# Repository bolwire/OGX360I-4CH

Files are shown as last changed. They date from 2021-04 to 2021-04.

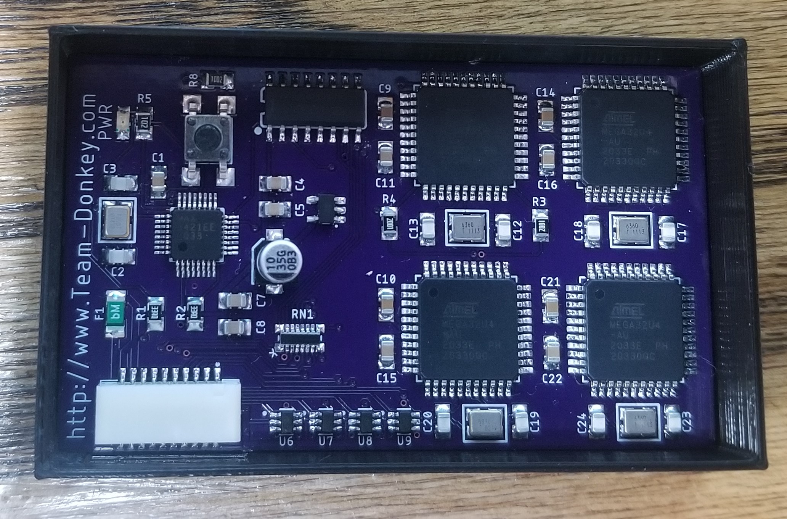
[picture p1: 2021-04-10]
Images/20210410_085733.jpg

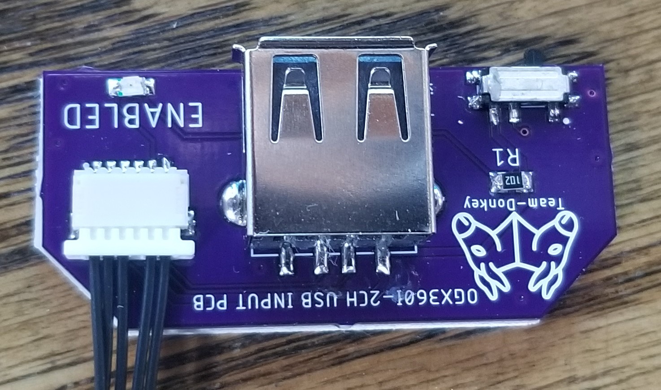
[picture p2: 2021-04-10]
Images/20210410_085617.jpg

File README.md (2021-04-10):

This project builds on the original OGX360 by Ryzee119: https://github.com/Ryzee119/ogx360/

The information provided in this repo is for informational purposes only.

The ATMEGA32U4 chips will need to be programmed with the arduino bootloader before they are put on the PCB. One option may be to remove the chips
from an arduino and transplant them.

Please respect the license files found within this project. What we do, and the joy we gain from that would not be possible without those who shared the
information with us to start with. Please respect and honor that by doing the same with any works derived from this or other projects linked to in this repo.

Also my spelling sucks, so I apologize for any type-ohs that exist.

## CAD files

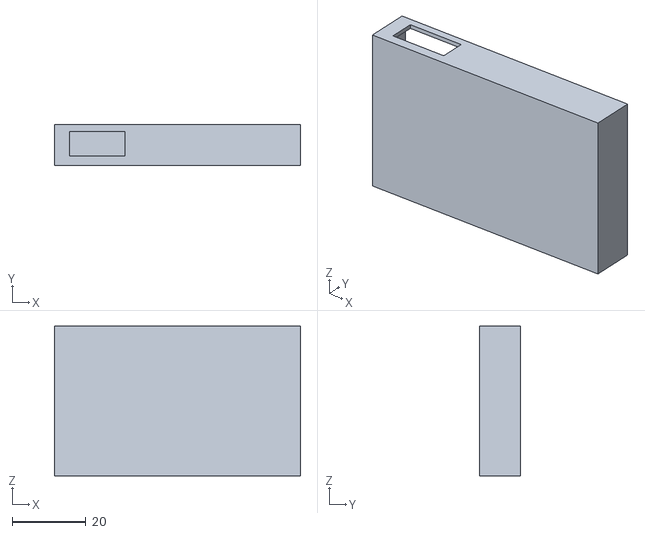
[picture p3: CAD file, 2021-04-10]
Case/Bottom.stl
66.5 x 11.2 x 40.5

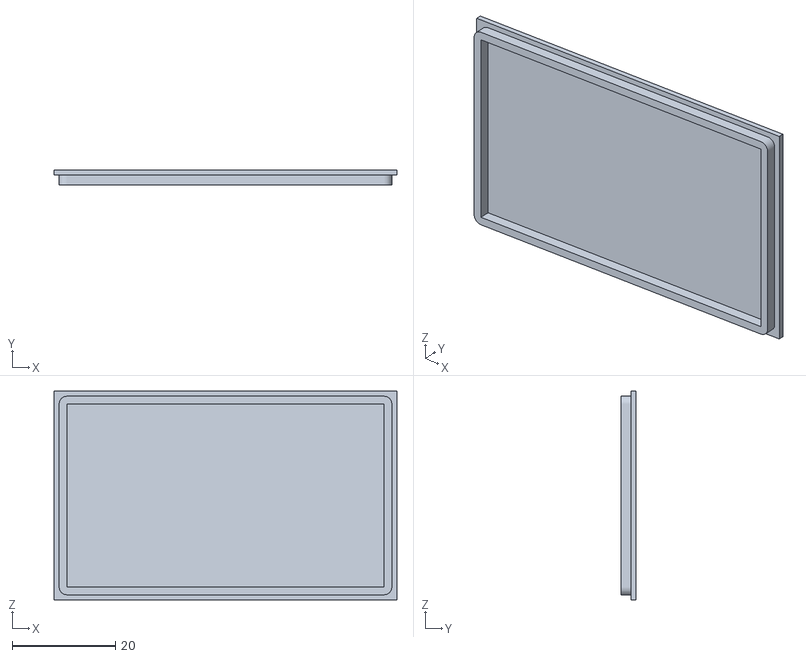
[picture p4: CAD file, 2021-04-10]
Case/Top.stl
66.5 x 3.00 x 40.5

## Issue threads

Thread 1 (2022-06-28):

Any more Documentation?

dtomcat, 2022-06-28:
Is there anymore documentation for this anywhere?  I'd like to make one, but there really isn't any type of instructions, BOM, etc.  Just wanted to know if there is any information elsewhere to help build this?  I can gather most information from the .sch and .brd 's, but some things aren't documented (like x1... x5 freq and cable pinouts (last could probably be interpolated through all the .sch)).  And no mention at all (or photos) of programming utility board...  i'm assuming you jumper DN and DP to whichever player you want to program, but not sure about the ogx_disable jumper.
Thank you for any info

dtomcat, 2023-07-30:
https://github.com/dtomcat/OGX360I-4CH

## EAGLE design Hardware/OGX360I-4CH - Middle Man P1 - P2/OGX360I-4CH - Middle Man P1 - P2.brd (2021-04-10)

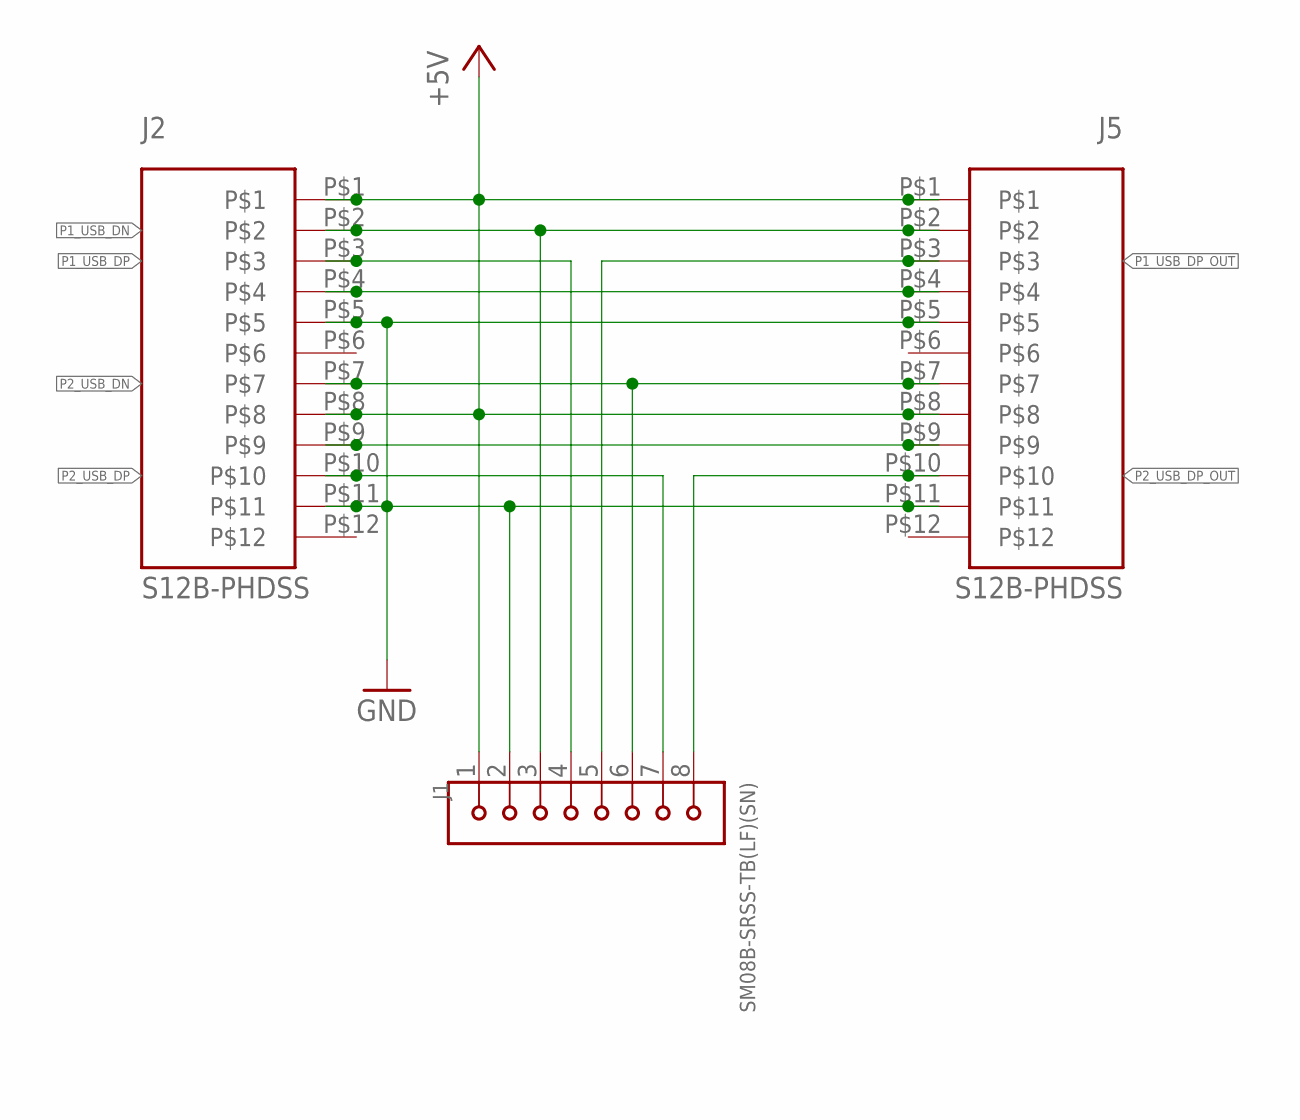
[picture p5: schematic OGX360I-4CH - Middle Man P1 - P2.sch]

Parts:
J1: SM08B-SRSS-TB(LF)(SN); JST_SM08B-SRSS-TB(LF)(SN)
J2, J5: S12B-PHDSS

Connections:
+5V: J1.1, J2.P$1, J2.P$8, J5.P$1, J5.P$8
GND: J1.2, J2.P$5, J2.P$11, J5.P$5, J5.P$11
unnamed: J2.P$4, J5.P$4
unnamed: J2.P$9, J5.P$9
P1_USB_DN: J1.3, J2.P$2, J5.P$2
P1_USB_DP: J1.4, J2.P$3
P1_USB_DP_OUT: J1.5, J5.P$3
P2_USB_DN: J1.6, J2.P$7, J5.P$7
P2_USB_DP: J1.7, J2.P$10
P2_USB_DP_OUT: J1.8, J5.P$10

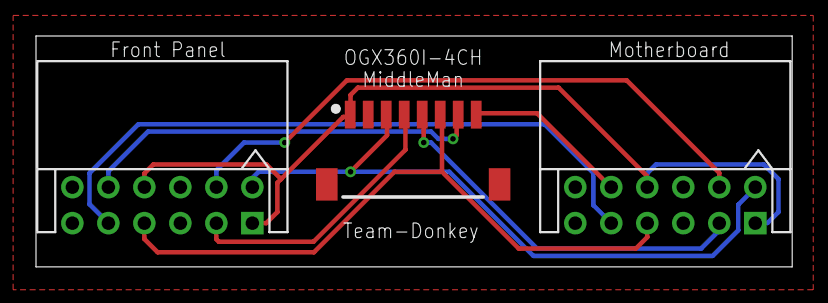
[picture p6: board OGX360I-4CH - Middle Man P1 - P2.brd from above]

Board: 2 copper layers, 42.0 x 12.8 mm, 3 parts (0 on the bottom side), 10 nets.

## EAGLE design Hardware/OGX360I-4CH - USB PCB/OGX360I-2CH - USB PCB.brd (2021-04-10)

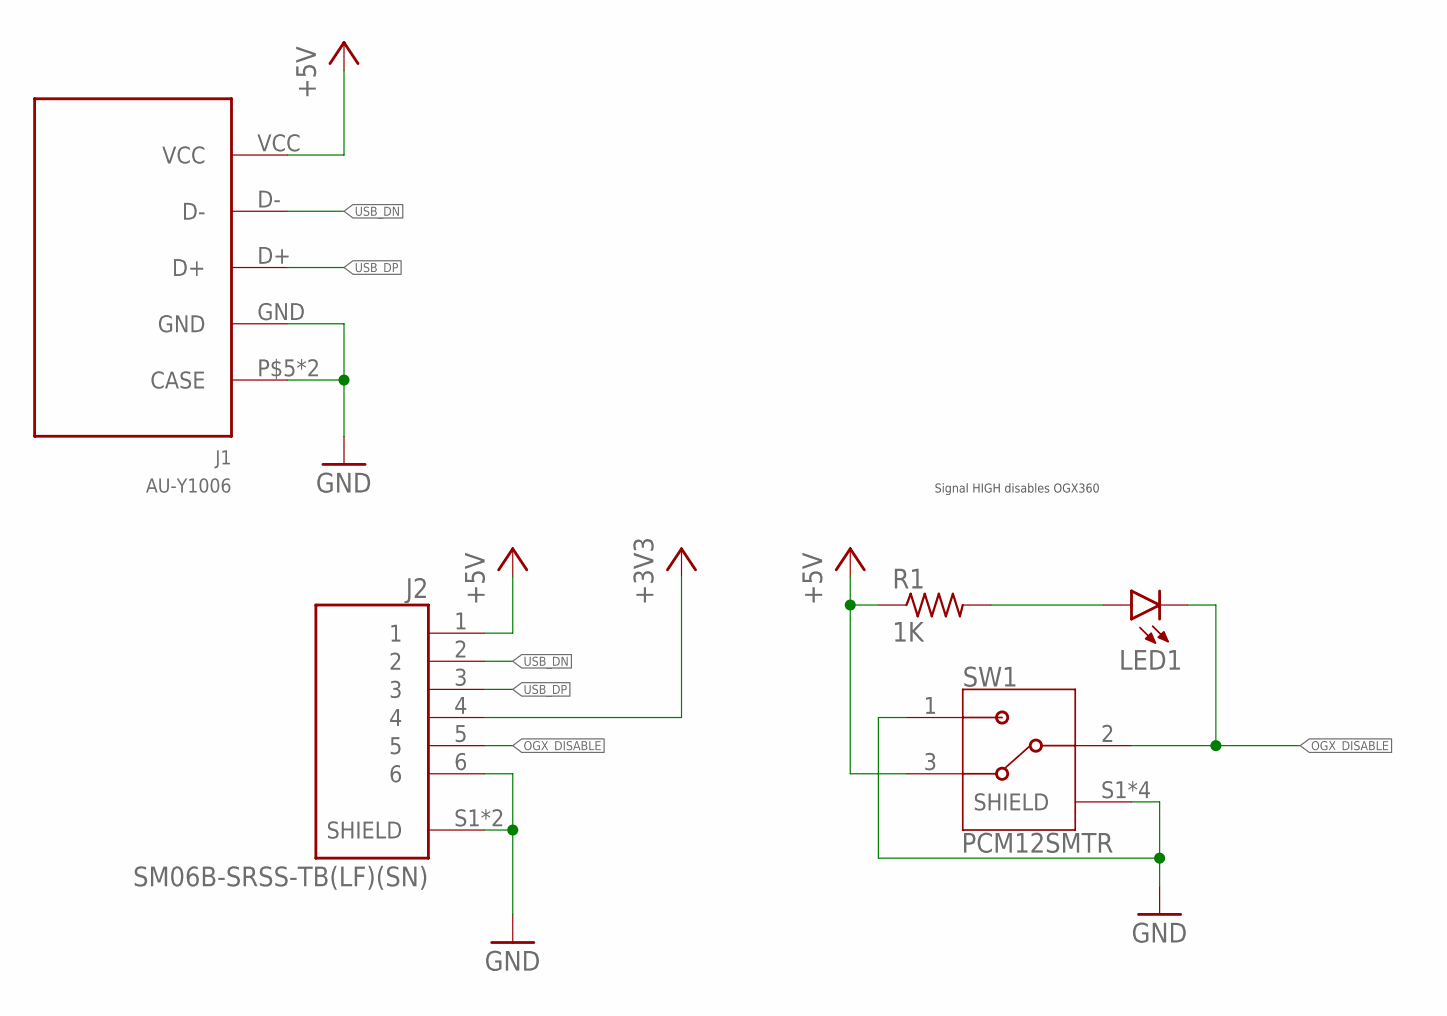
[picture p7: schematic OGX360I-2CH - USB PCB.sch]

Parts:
J1: AU-Y1006; USBA_SMD
J2: SM06B-SRSS-TB(LF)(SN); JST_SM06B-SRSS-TB(LF)(SN)
LED1: LEDCHIP-LED0805; CHIP-LED0805
R1: 1K; R0805
SW1: PCM12SMTR; SW_PCM12SMTR

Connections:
+3V3: J2.4
+5V: J1.VCC, J2.1, R1.1, SW1.3
GND: J1.GND, J1.P$5 (CASE), J1.P$6 (CASE), J2.6, J2.S1 (SHIELD), J2.S2 (SHIELD), SW1.1, SW1.S1 (SHIELD), SW1.S2 (SHIELD), SW1.S3 (SHIELD), SW1.S4 (SHIELD)
unnamed: LED1.A, R1.2
OGX_DISABLE: J2.5, LED1.C, SW1.2
USB_DN: J1.D-, J2.2
USB_DP: J1.D+, J2.3

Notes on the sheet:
Signal HIGH disables OGX360

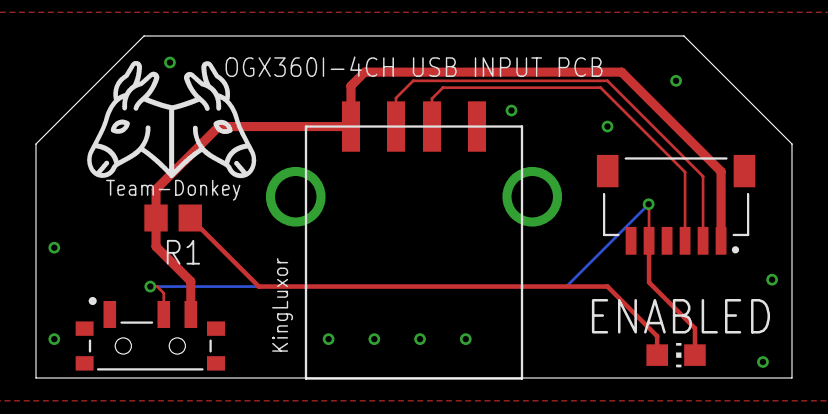
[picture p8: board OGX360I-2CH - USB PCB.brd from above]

Board: 2 copper layers, 42.0 x 19.0 mm, 5 parts (0 on the bottom side), 6 nets.

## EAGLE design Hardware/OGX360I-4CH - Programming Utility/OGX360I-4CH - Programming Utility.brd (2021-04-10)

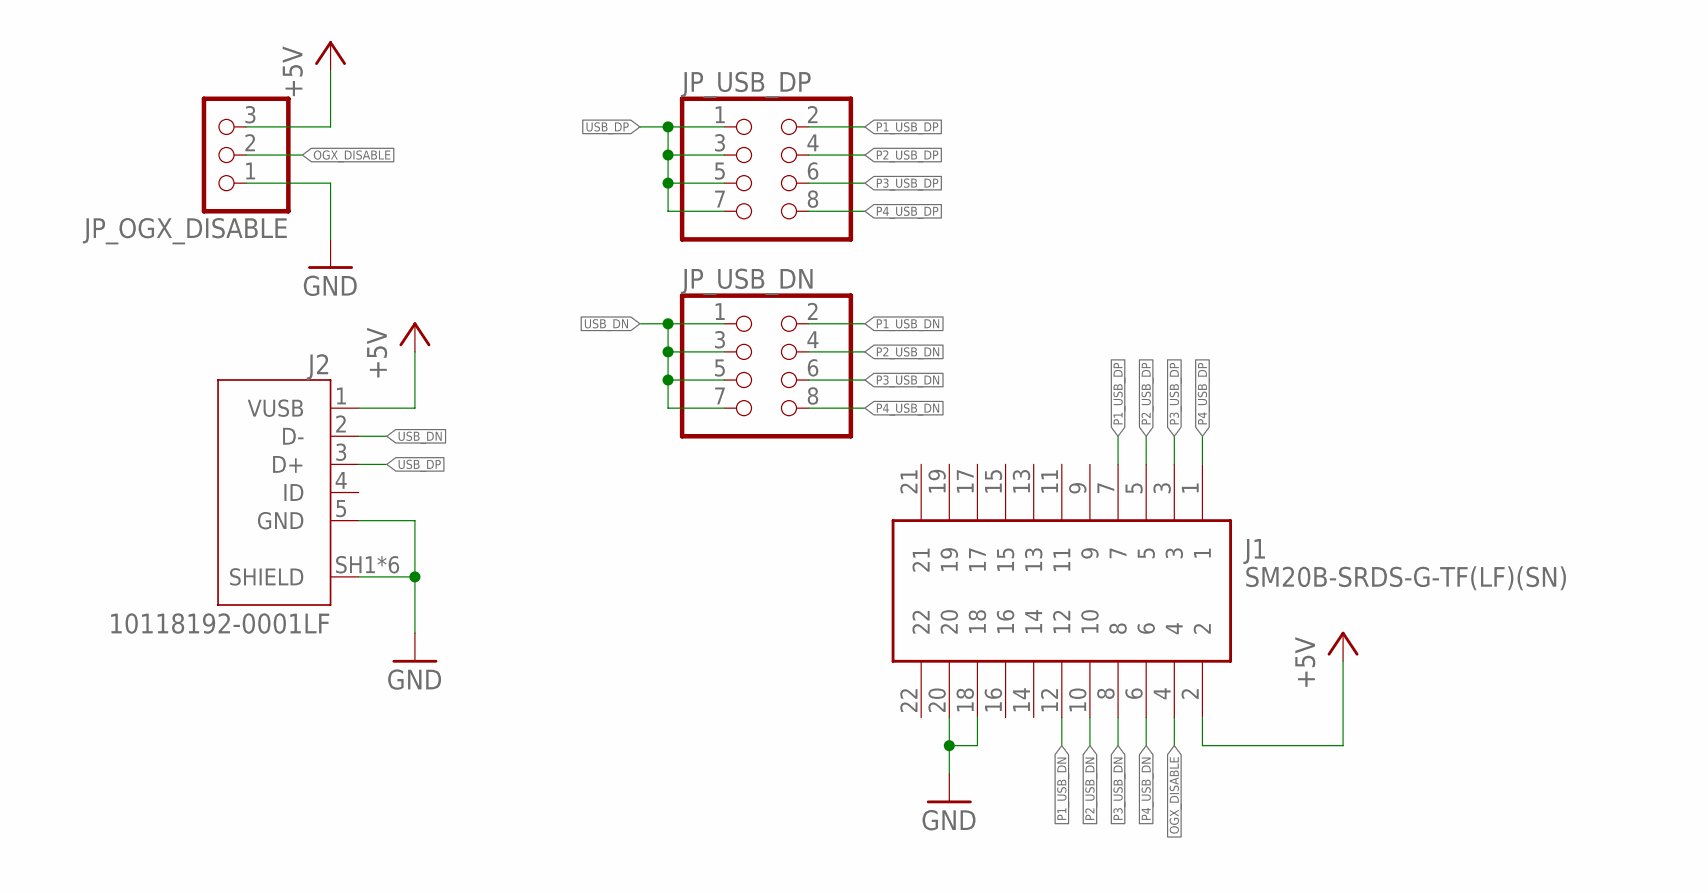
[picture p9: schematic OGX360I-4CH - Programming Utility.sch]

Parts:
J1: SM20B-SRDS-G-TF(LF)(SN); SM20BSRDSGTFLFSN
J2: 10118192-0001LF; AMPHENOL_10118192-0001LF
JP_OGX_DISABLE: PINHD-1X3; 1X03
JP_USB_DN: PINHD-2X4; 2X04
JP_USB_DP: PINHD-2X4; 2X04

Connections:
+5V: J1.2, J2.1 (VUSB), JP_OGX_DISABLE.3
GND: J1.18, J1.20, J2.5 (GND), J2.SH1 (SHIELD), J2.SH2 (SHIELD), J2.SH3 (SHIELD), J2.SH4 (SHIELD), J2.SH5 (SHIELD), J2.SH6 (SHIELD), JP_OGX_DISABLE.1
OGX_DISABLE: J1.4, JP_OGX_DISABLE.2
P1_USB_DN: J1.12, JP_USB_DN.2
P1_USB_DP: J1.7, JP_USB_DP.2
P2_USB_DN: J1.10, JP_USB_DN.4
P2_USB_DP: J1.5, JP_USB_DP.4
P3_USB_DN: J1.8, JP_USB_DN.6
P3_USB_DP: J1.3, JP_USB_DP.6
P4_USB_DN: J1.6, JP_USB_DN.8
P4_USB_DP: J1.1, JP_USB_DP.8
USB_DN: J2.2 (D-), JP_USB_DN.1, JP_USB_DN.3, JP_USB_DN.5, JP_USB_DN.7
USB_DP: J2.3 (D+), JP_USB_DP.1, JP_USB_DP.3, JP_USB_DP.5, JP_USB_DP.7

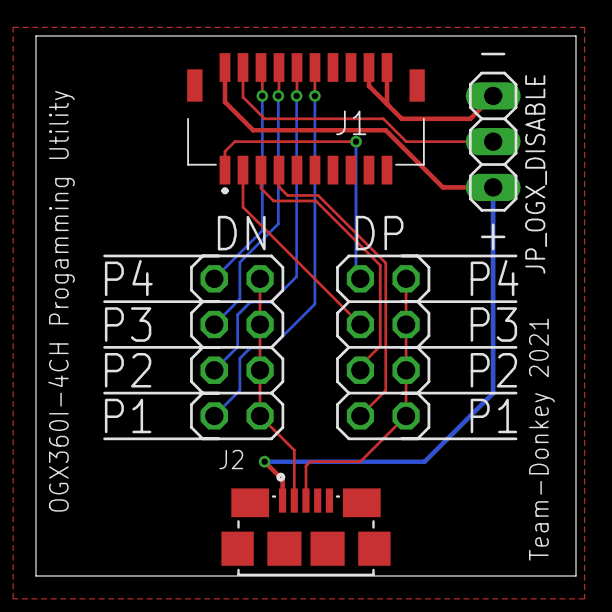
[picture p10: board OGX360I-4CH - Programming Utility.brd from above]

Board: 2 copper layers, 30.0 x 30.0 mm, 5 parts (0 on the bottom side), 13 nets.

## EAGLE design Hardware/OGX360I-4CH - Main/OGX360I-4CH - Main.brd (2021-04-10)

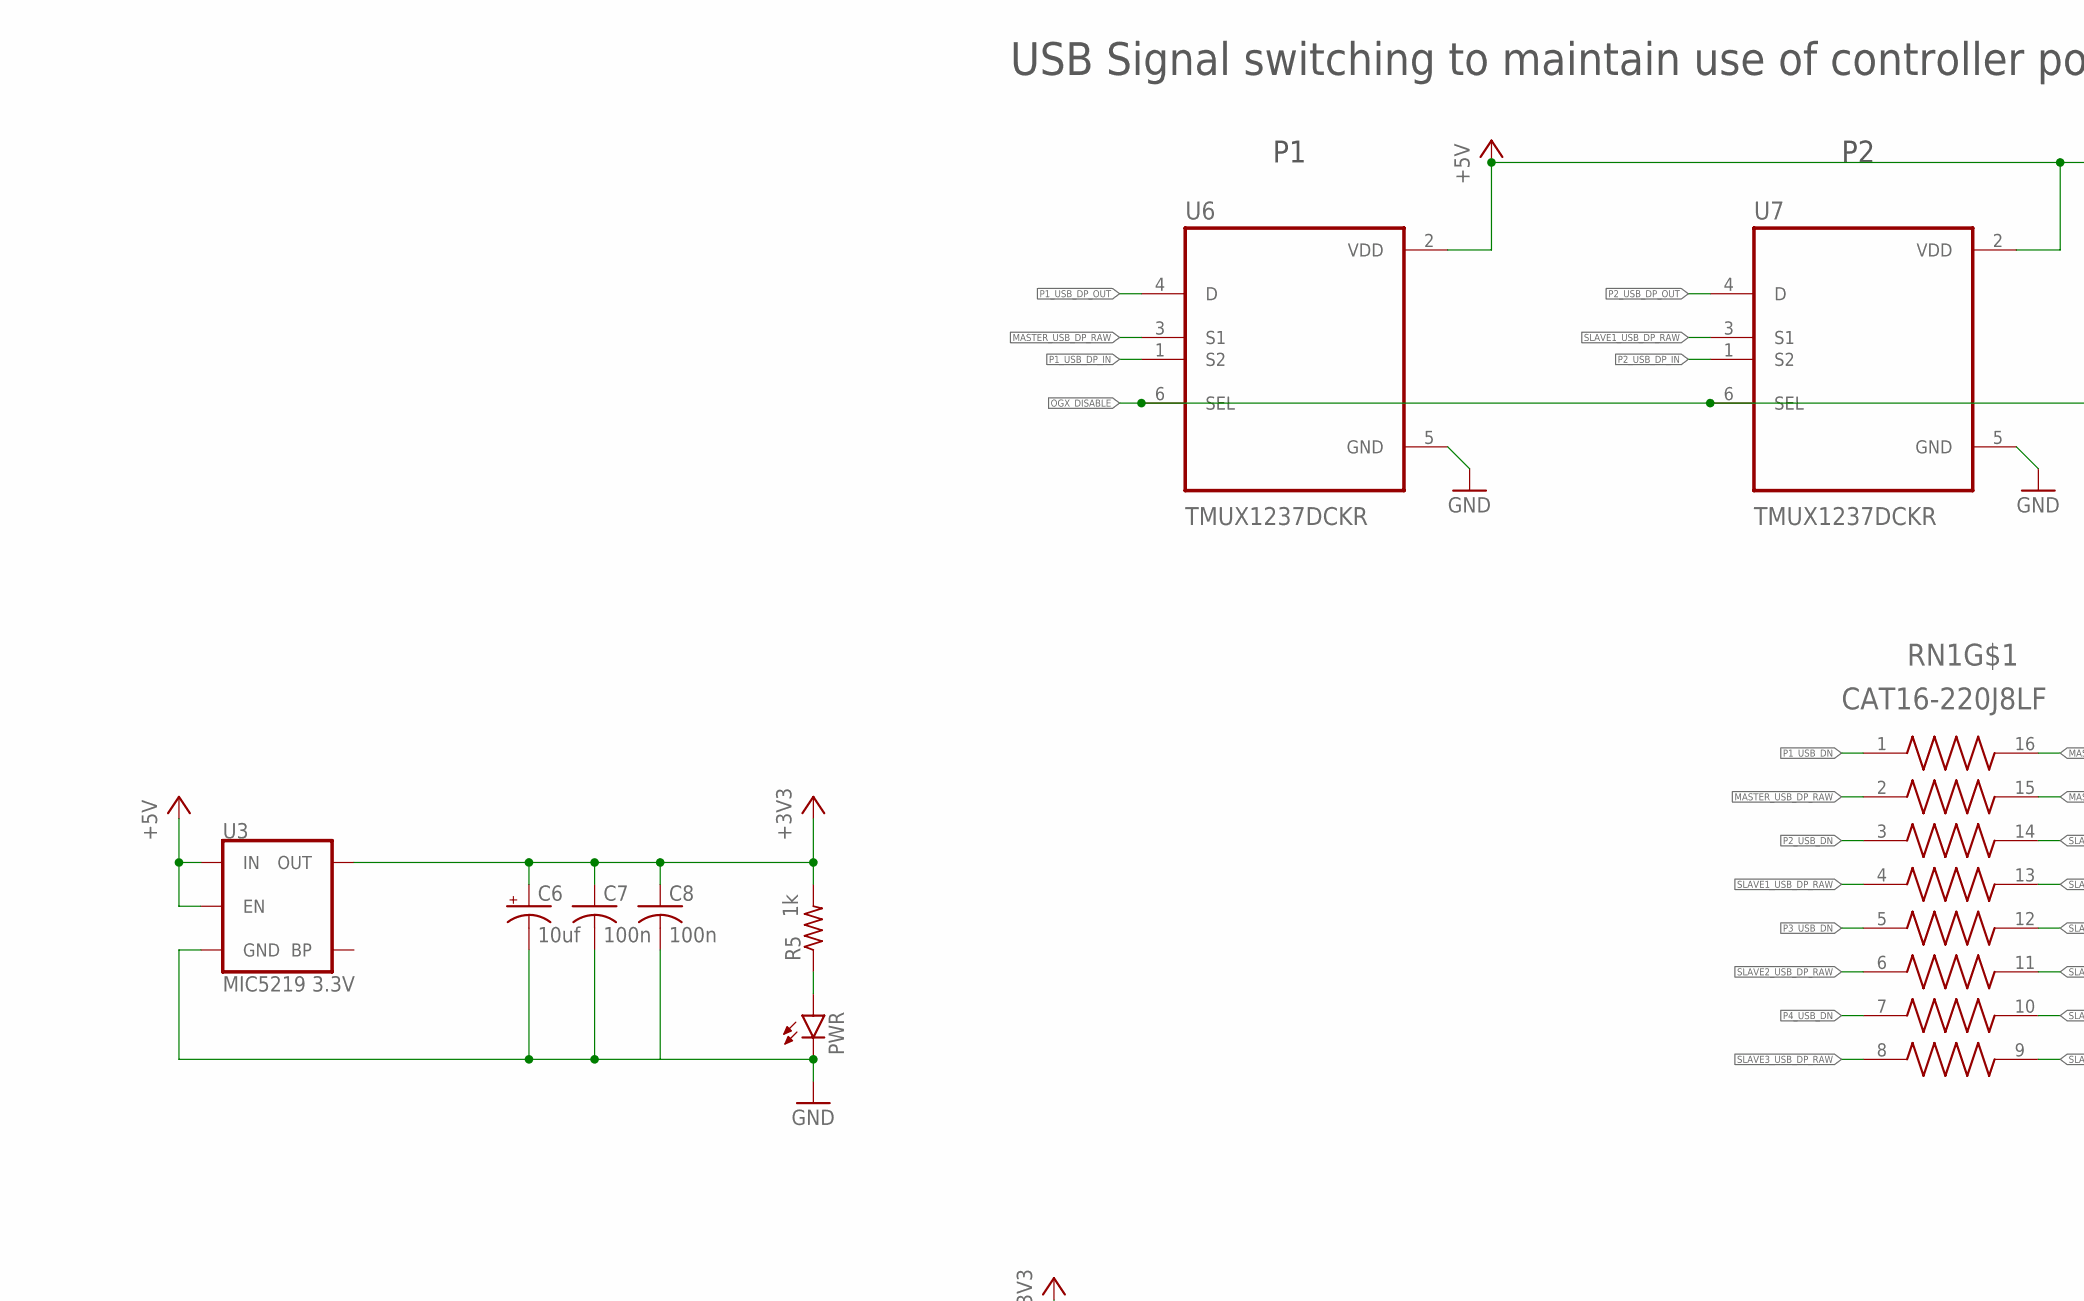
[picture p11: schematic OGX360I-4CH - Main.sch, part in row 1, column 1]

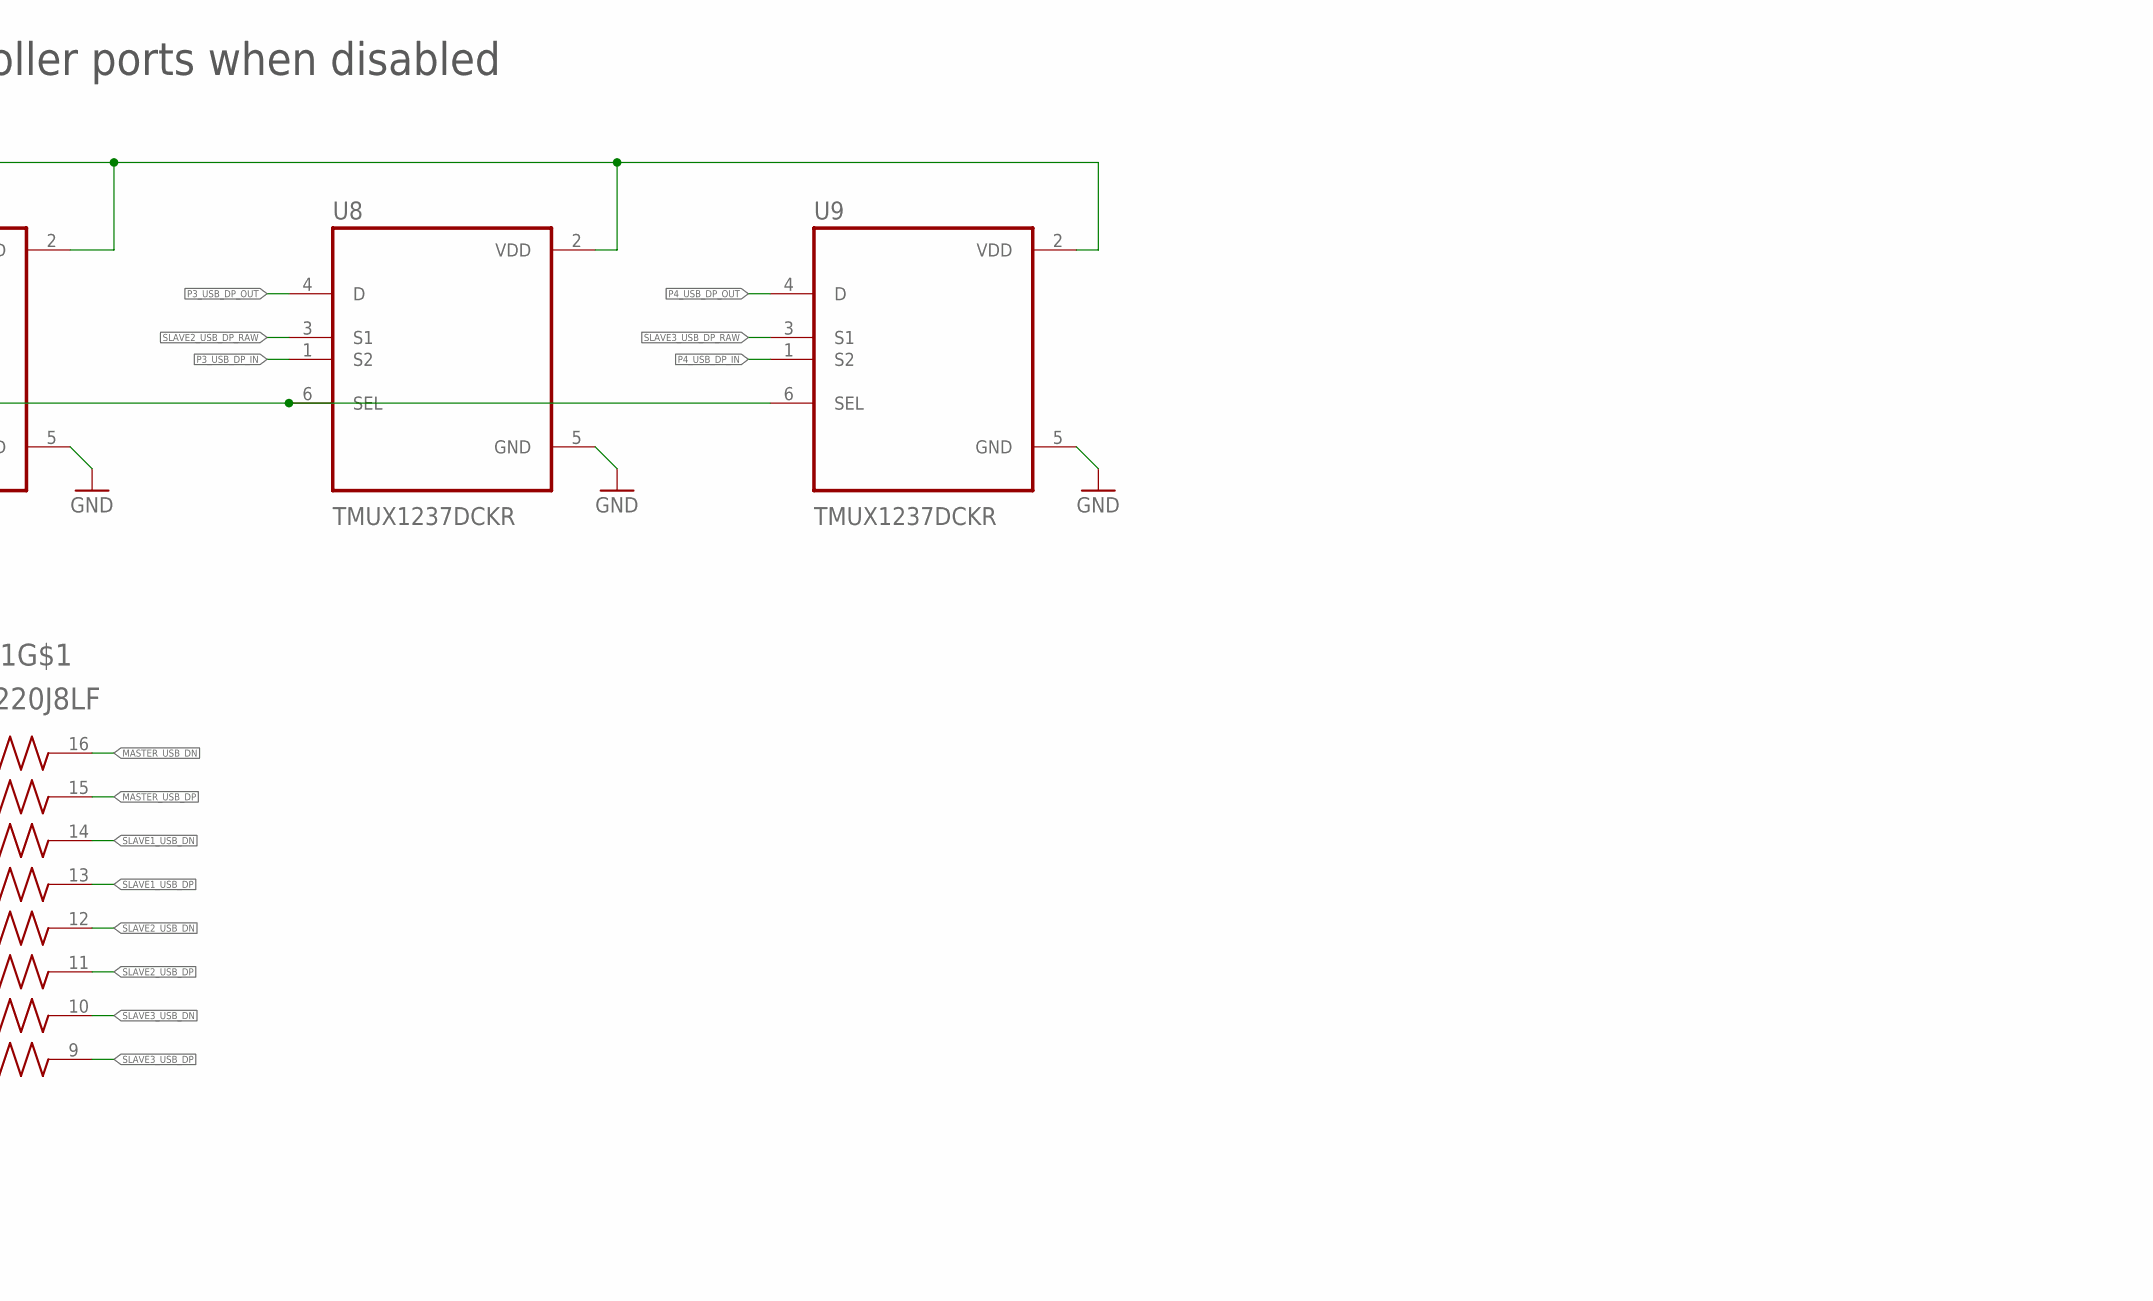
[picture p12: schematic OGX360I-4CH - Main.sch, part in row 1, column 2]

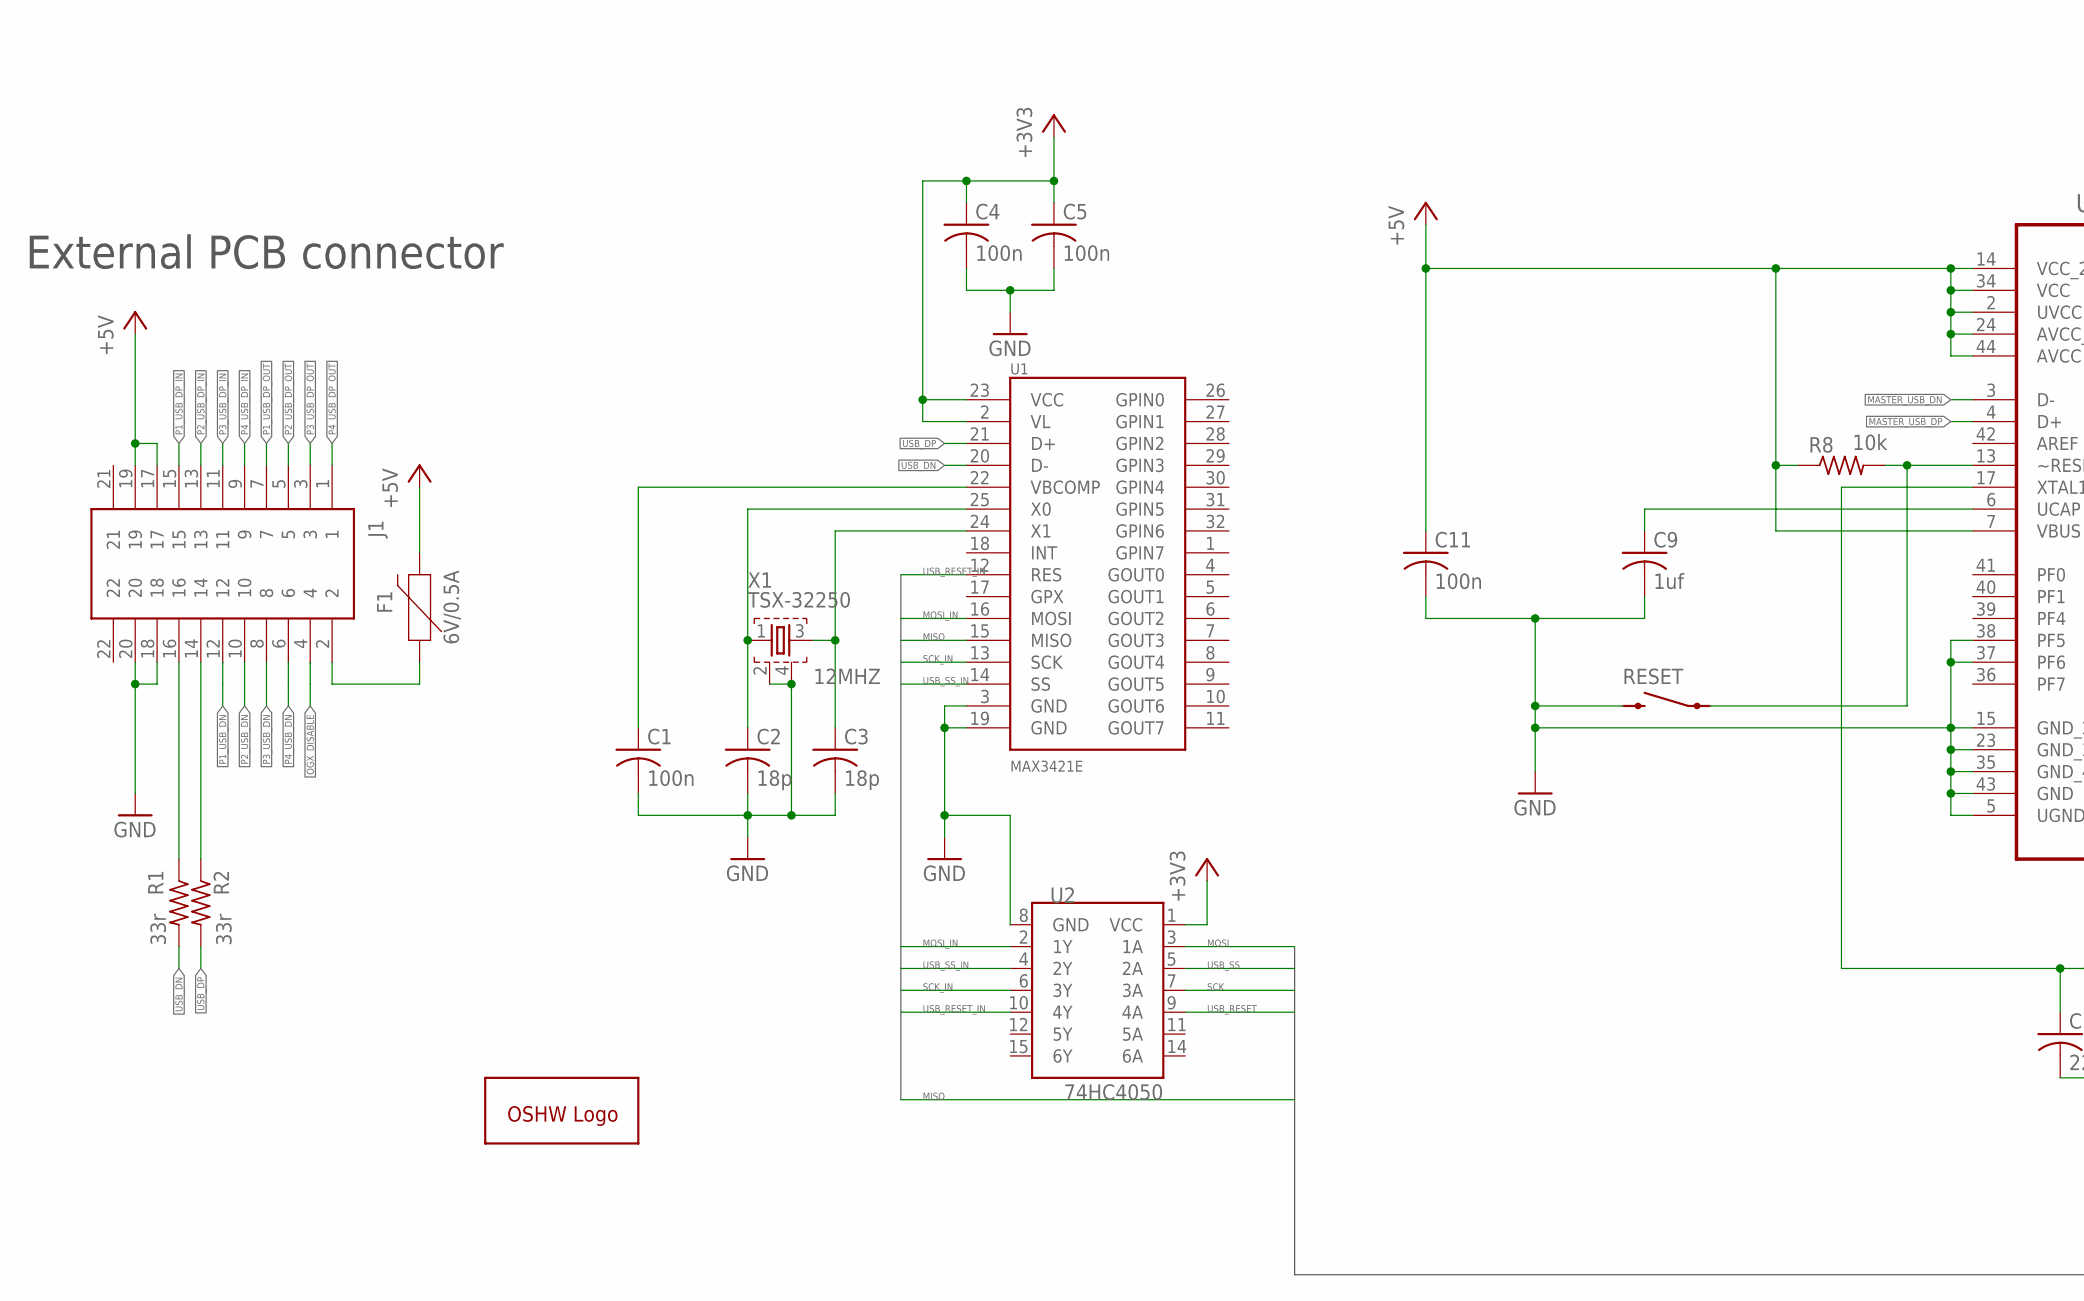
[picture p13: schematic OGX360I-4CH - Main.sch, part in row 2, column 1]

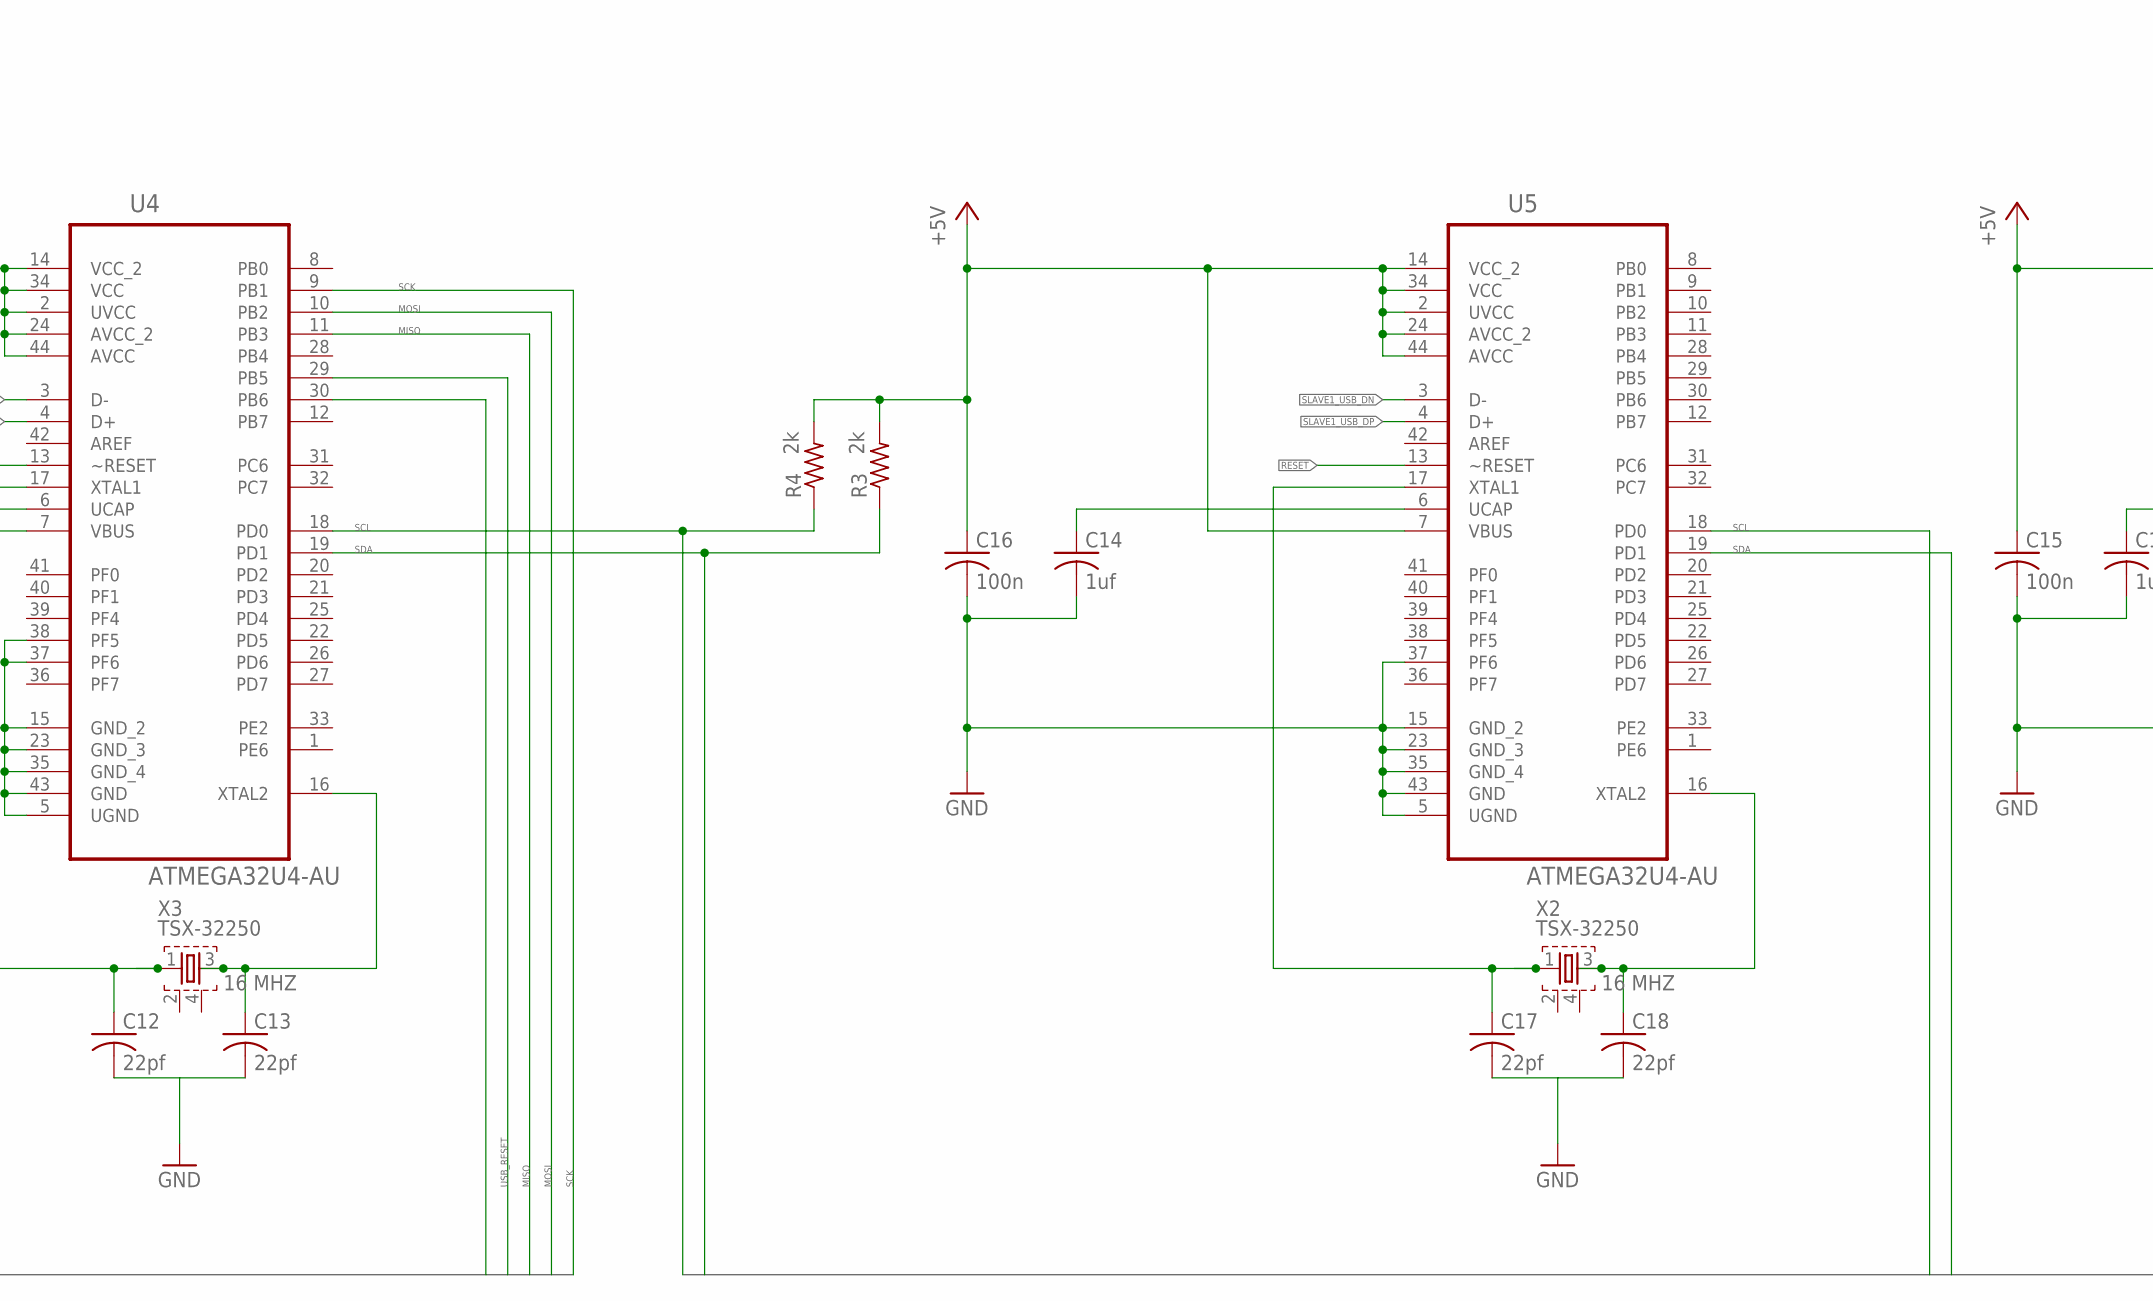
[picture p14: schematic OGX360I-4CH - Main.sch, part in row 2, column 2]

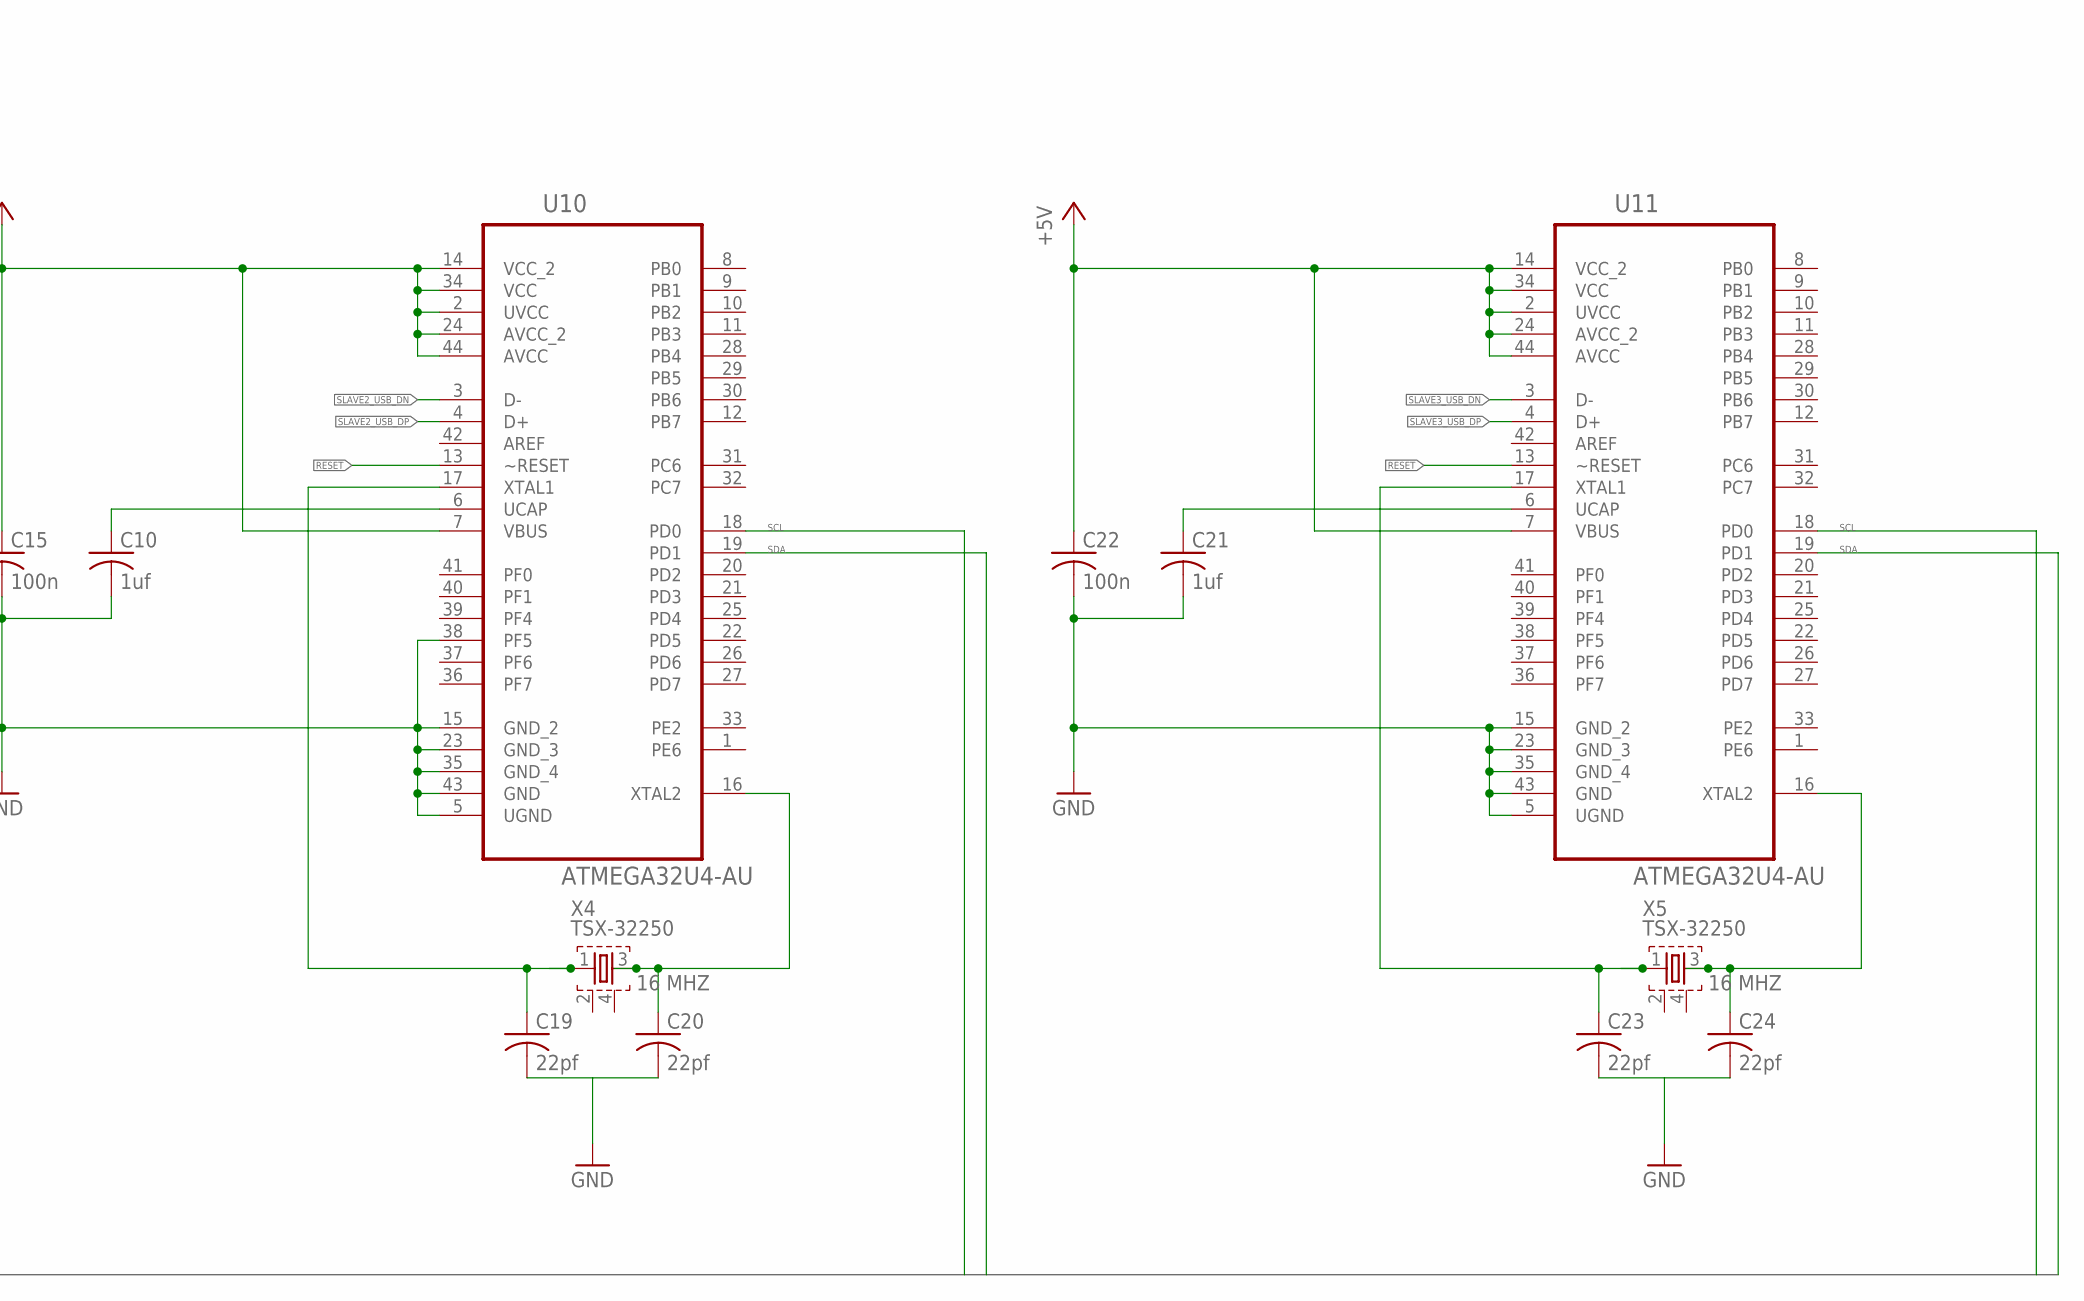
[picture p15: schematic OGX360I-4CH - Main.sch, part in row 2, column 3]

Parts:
C1, C4, C5, C7, C8, C11, C15, C16, C22: 100n; C0805
C2, C3: 18p; C0805
C6: 10uf; 153CLV-0405
C9, C10, C14, C21: 1uf; C0805
C12, C13, C17, C18, C19, C20, C23, C24: 22pf; C0805
F1: 6V/0.5A; 1206
GOLD_ORB_SM1: OSHWLOGOLOGO8MM; OSHW_8MM
J1: SM20B-SRDS-G-TF(LF)(SN); SM20BSRDSGTFLFSN
PWR: LEDCHIP-LED0805; CHIP-LED0805
R1, R2: 33r; M0805
R3, R4: 2k; M0805
R5: 1k; M0805
R8: 10k; M0805
RESET: TL3305AF160QG
RN1: CAT16-220J8LF; RESCAV80P640X160X75-16N
U1: MAX3421E; TQFP32-5MM
U2: 74HC4050; SO16
U3: MIC5219 3.3V; SOT23-5
U4, U5, U10, U11: ATMEGA32U4-AU; QFP80P1200X1200X120-44N
U6, U7, U8, U9: TMUX1237DCKR; SOT65P210X110-6N
X1, X2, X3, X4, X5: TSX-32250; TSX-3225

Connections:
+3V3: C4.1, C5.1, C6.+, C7.1, C8.1, R5.2, U1.2 (VL), U1.23 (VCC), U2.1 (VCC), U3.5 (OUT)
+5V: C11.1, C15.1, C16.1, C22.1, F1.2, J1.17, J1.19, R3.2, R4.2, R8.1, U3.1 (IN), U3.3 (EN), U4.2 (UVCC), U4.7 (VBUS), U4.14 (VCC_2), U4.24 (AVCC_2), U4.34 (VCC), U4.44 (AVCC), U5.2 (UVCC), U5.7 (VBUS), U5.14 (VCC_2), U5.24 (AVCC_2), U5.34 (VCC), U5.44 (AVCC), U6.2 (VDD), U7.2 (VDD), U8.2 (VDD), U9.2 (VDD), U10.2 (UVCC), U10.7 (VBUS), U10.14 (VCC_2), U10.24 (AVCC_2), U10.34 (VCC), U10.44 (AVCC), U11.2 (UVCC), U11.7 (VBUS), U11.14 (VCC_2), U11.24 (AVCC_2), U11.34 (VCC), U11.44 (AVCC)
EXT_USB_DN: J1.16, R1.1
EXT_USB_DP: J1.14, R2.1
FUSED_+5V: F1.1, J1.2
GND: C1.2, C2.2, C3.2, C4.2, C5.2, C6.-, C7.2, C8.2, C9.2, C10.2, C11.2, C12.2, C13.2, C14.2, C15.2, C16.2, C17.2, C18.2, C19.2, C20.2, C21.2, C22.2, C23.2, C24.2, J1.18, J1.20, PWR.C, RESET.P$1, RESET.P$2, U1.3 (GND), U1.19 (GND), U2.8 (GND), U3.2 (GND), U4.5 (UGND), U4.15 (GND_2), U4.23 (GND_3), U4.35 (GND_4), U4.37 (PF6), U4.38 (PF5), U4.43 (GND), U5.5 (UGND), U5.15 (GND_2), U5.23 (GND_3), U5.35 (GND_4), U5.37 (PF6), U5.43 (GND), U6.5 (GND), U7.5 (GND), U8.5 (GND), U9.5 (GND), U10.5 (UGND), U10.15 (GND_2), U10.23 (GND_3), U10.35 (GND_4), U10.38 (PF5), U10.43 (GND), U11.5 (UGND), U11.15 (GND_2), U11.23 (GND_3), U11.35 (GND_4), U11.43 (GND), X1.2, X1.4
MASTER_USB_DN: RN1.16 (R1-2), U4.3 (D-)
MASTER_USB_DP: RN1.15 (R2-2), U4.4 (D+)
MASTER_USB_DP_RAW: RN1.2 (R2-1), U6.3 (S1)
MISO: U1.15 (MISO), U4.11 (PB3)
MOSI: U2.3 (1A), U4.10 (PB2)
MOSI_IN: U1.16 (MOSI), U2.2 (1Y)
unnamed: C13.1, U4.16 (XTAL2), X3.3
unnamed: C3.1, U1.24 (X1), X1.3
unnamed: C10.1, U10.6 (UCAP)
unnamed: PWR.A, R5.1
unnamed: C2.1, U1.25 (X0), X1.1
unnamed: C1.1, U1.22 (VBCOMP)
unnamed: C20.1, U10.16 (XTAL2), X4.3
unnamed: C19.1, U10.17 (XTAL1), X4.1
unnamed: C9.1, U4.6 (UCAP)
unnamed: C21.1, U11.6 (UCAP)
unnamed: C24.1, U11.16 (XTAL2), X5.3
unnamed: C23.1, U11.17 (XTAL1), X5.1
unnamed: C12.1, U4.17 (XTAL1), X3.1
unnamed: C14.1, U5.6 (UCAP)
unnamed: C18.1, U5.16 (XTAL2), X2.3
unnamed: C17.1, U5.17 (XTAL1), X2.1
OGX_DISABLE: J1.4, U6.6 (SEL), U7.6 (SEL), U8.6 (SEL), U9.6 (SEL)
P1_USB_DN: J1.12, RN1.1 (R1-1)
P1_USB_DP_IN: J1.15, U6.1 (S2)
P1_USB_DP_OUT: J1.7, U6.4 (D)
P2_USB_DN: J1.10, RN1.3 (R3-1)
P2_USB_DP_IN: J1.13, U7.1 (S2)
P2_USB_DP_OUT: J1.5, U7.4 (D)
P3_USB_DN: J1.8, RN1.5 (R5-1)
P3_USB_DP_IN: J1.11, U8.1 (S2)
P3_USB_DP_OUT: J1.3, U8.4 (D)
P4_USB_DN: J1.6, RN1.7 (R7-1)
P4_USB_DP_IN: J1.9, U9.1 (S2)
P4_USB_DP_OUT: J1.1, U9.4 (D)
RESET: R8.2, RESET.P$3 (2), RESET.P$4 (2), U4.13 (~RESET), U5.13 (~RESET), U10.13 (~RESET), U11.13 (~RESET)
SCK: U2.7 (3A), U4.9 (PB1)
SCK_IN: U1.13 (SCK), U2.6 (3Y)
SCL: R4.1, U4.18 (PD0), U5.18 (PD0), U10.18 (PD0), U11.18 (PD0)
SDA: R3.1, U4.19 (PD1), U5.19 (PD1), U10.19 (PD1), U11.19 (PD1)
SLAVE1_USB_DN: RN1.14 (R3-2), U5.3 (D-)
SLAVE1_USB_DP: RN1.13 (R4-2), U5.4 (D+)
SLAVE1_USB_DP_RAW: RN1.4 (R4-1), U7.3 (S1)
SLAVE2_USB_DN: RN1.12 (R5-2), U10.3 (D-)
SLAVE2_USB_DP: RN1.11 (R6-2), U10.4 (D+)
SLAVE2_USB_DP_RAW: RN1.6 (R6-1), U8.3 (S1)
SLAVE3_USB_DN: RN1.10 (R7-2), U11.3 (D-)
SLAVE3_USB_DP: RN1.9 (R8-2), U11.4 (D+)
SLAVE3_USB_DP_RAW: RN1.8 (R8-1), U9.3 (S1)
USB_DN: R1.2, U1.20 (D-)
USB_DP: R2.2, U1.21 (D+)
USB_RESET: U2.9 (4A), U4.29 (PB5)
USB_RESET_IN: U1.12 (RES), U2.10 (4Y)
USB_SS: U2.5 (2A), U4.30 (PB6)
USB_SS_IN: U1.14 (SS), U2.4 (2Y)

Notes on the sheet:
12MHZ
16 MHZ
USB Signal switching to maintain use of controller ports when disabled
External PCB connector

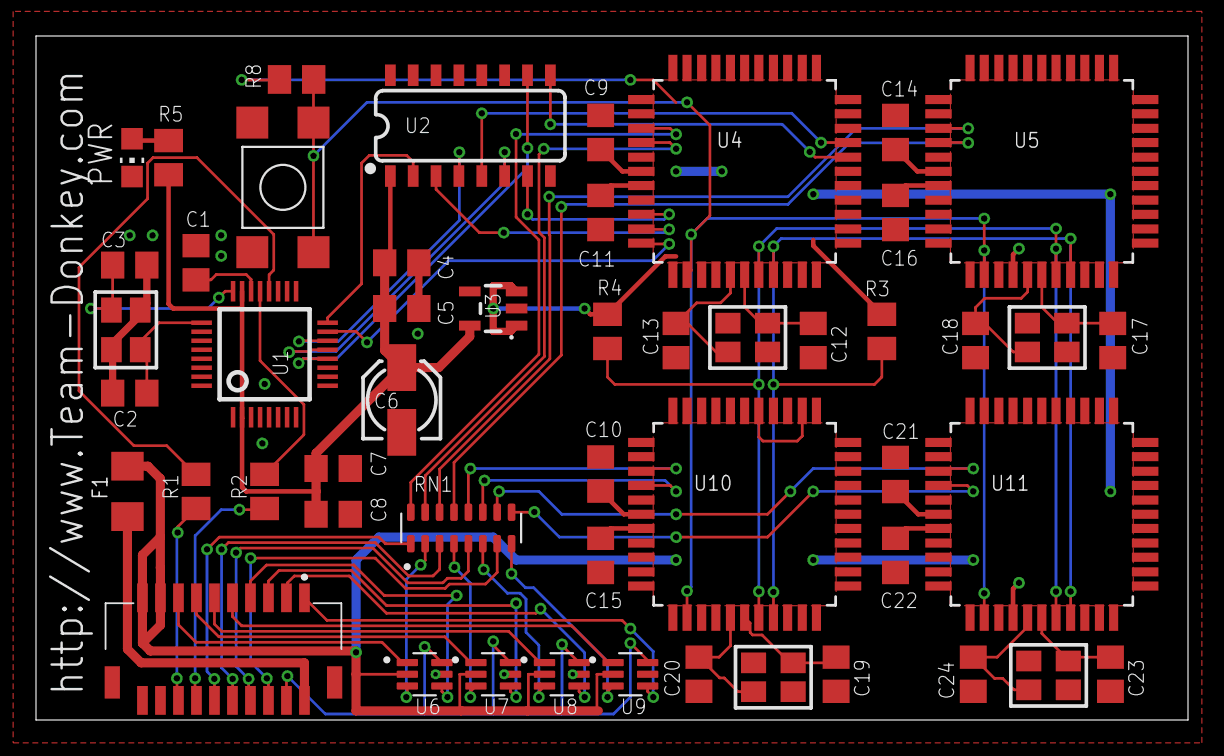
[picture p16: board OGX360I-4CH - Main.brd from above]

Board: 2 copper layers, 64.0 x 38.0 mm, 52 parts (1 on the bottom side), 61 nets.

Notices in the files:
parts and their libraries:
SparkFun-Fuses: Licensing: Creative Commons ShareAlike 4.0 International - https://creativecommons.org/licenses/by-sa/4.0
